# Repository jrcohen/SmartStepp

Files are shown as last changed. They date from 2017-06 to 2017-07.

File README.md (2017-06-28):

# SmartStepp

### Combination Driver and Encoder for Nema 17 stepper motors
Features:

 * Compact design mounts on the back of the motor
 * Chainable connections (12V Power, Logic Power, SPI) - Hook up multiple motors in series connected to just one microcontroller
 * Compatible with A4988 and DRV8825 stepper motor drivers
 * 14-bit magnetic encoder (AS5047d)
 * Encoder only version is RAMPS 1.4 compatible 

The aim of this project is to create inexpensive Nema 17 and Nema 23 motor encoders/drivers. These boards allow for plug-and-play stepper motor control with extremely precise position readouts once fully calibrated. 

Useful for 3D printers to provide higher precision movement and dynamic error correction for any missed steps (like if the printer gets bumped or stops mid-print).
Other potential applications include robotics/robot arms, process automation machines, hobby CNC machines, any other application needing precise repeatability under different loads.

Project hardware variants:

 * Motor driver only - target cost under $10
 * Encoder only - target cost under $15
 * Driver/Encoder combo - target cost under $20

Future Software compatibility:

 * Arduino Library
 * Python Library (for standalone raspberry pi use)
 * Marlin 
 * GRBL
 
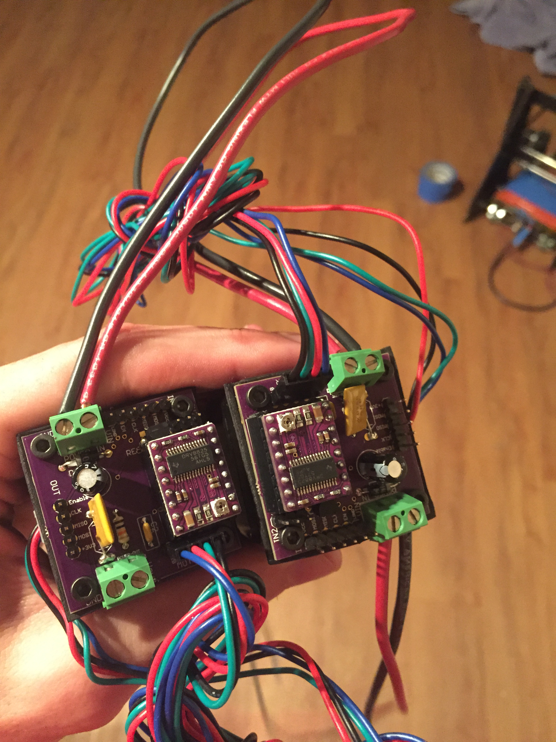
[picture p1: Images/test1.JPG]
Prototype


This project draws inspiration from [Mechaduino](https://github.com/jcchurch13/Mechaduino-Firmware/blob/master/README.md), but hopefully will have its own niche applications

Released under the Creative Commons Attribution Share-Alike 4.0 License

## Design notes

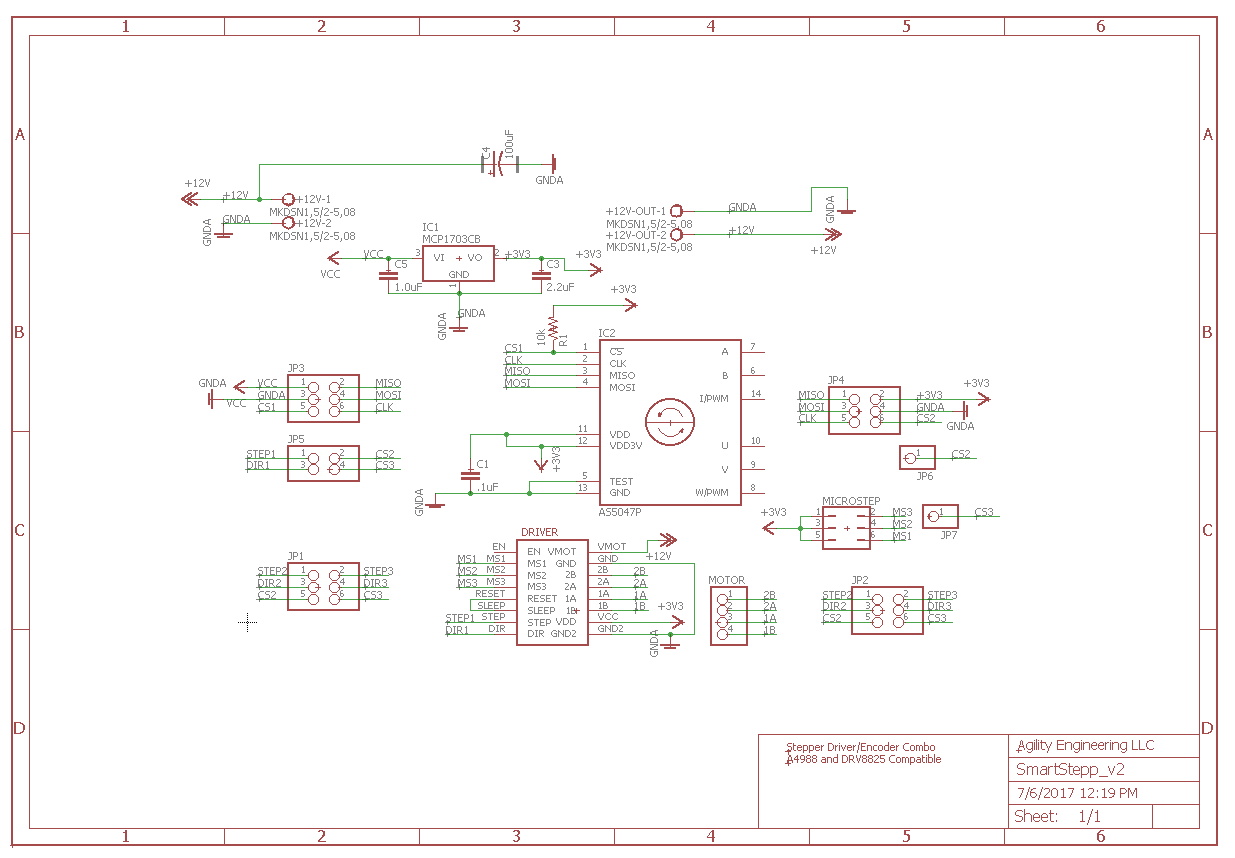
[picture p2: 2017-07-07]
Hardware/SmartStepp_V2_Schematic.PNG

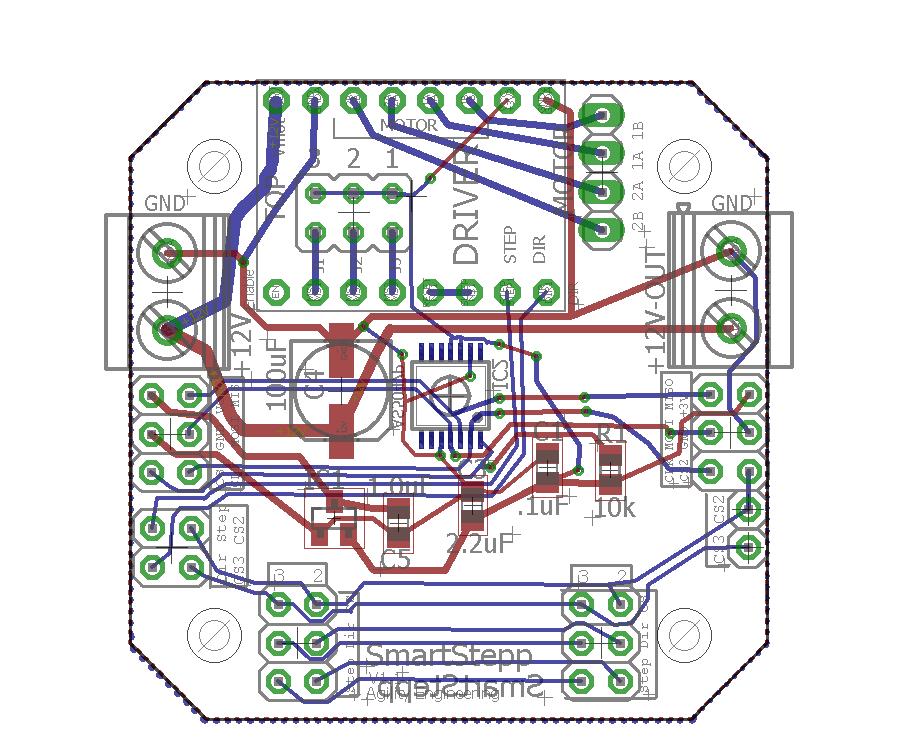
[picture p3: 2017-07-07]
Hardware/SmartStepp_V2_Board.PNG

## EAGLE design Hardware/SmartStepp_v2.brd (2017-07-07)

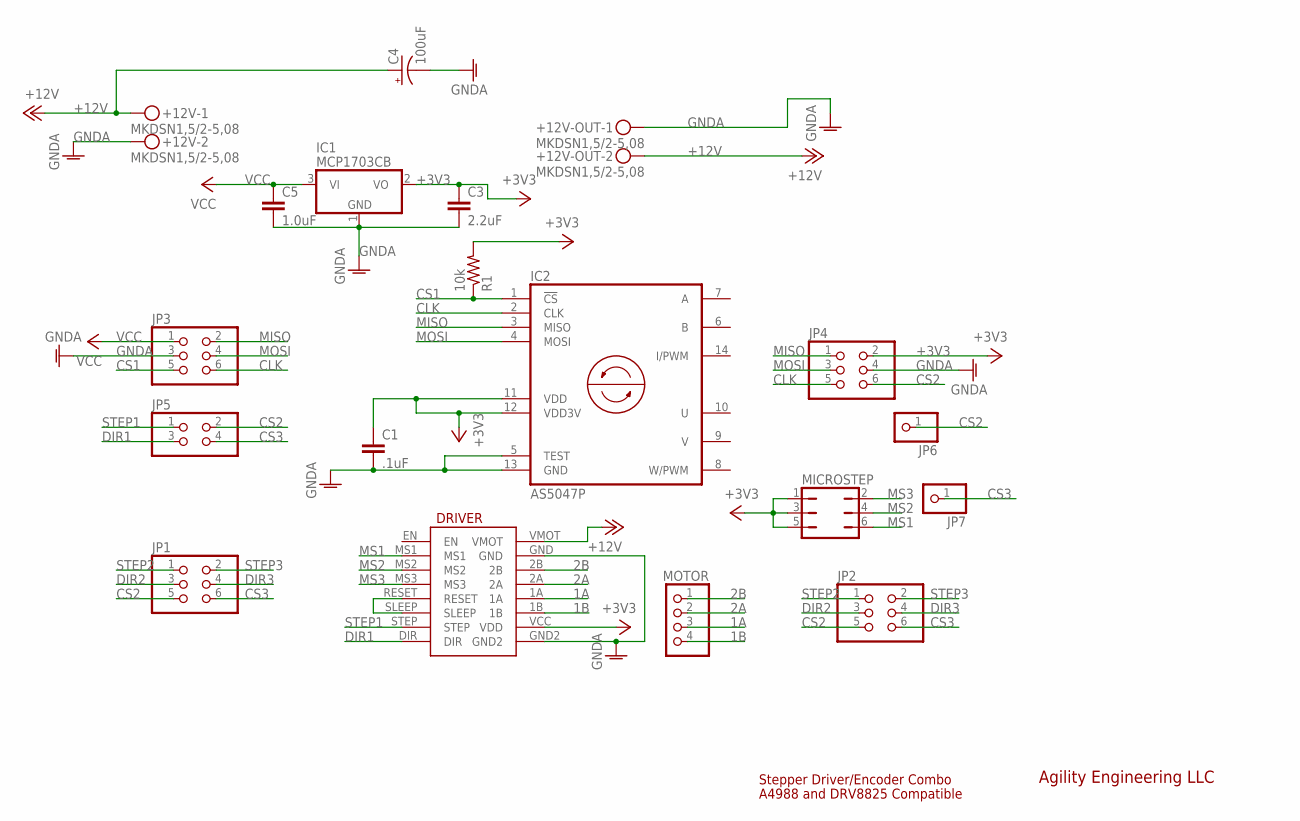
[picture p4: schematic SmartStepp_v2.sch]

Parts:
+12V, +12V-OUT: MKDSN1,5/2-5,08
C1: .1uF; C0805
C3: 2.2uF; C0805
C4: 100uF; 153CLV-0605
C5: 1.0uF; C0805
DRIVER: A4988; MOTOR_DRIVER
IC1: MCP1703CB; SOT23
IC2: AS5047P; TSSOP14
JP1, JP2, JP3, JP4: PINHD-2X3; 2X03
JP5: PINHD-2X2; 2X02
JP6, JP7: PINHD-1X1; 1X01
MICROSTEP: JP3Q
MOTOR: PINHD-1X4; 1X04
R1: 10k; R0805

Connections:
1A: DRIVER.1A, MOTOR.3
1B: DRIVER.1B, MOTOR.4
2A: DRIVER.2A, MOTOR.2
2B: DRIVER.2B, MOTOR.1
+3V3: C1.1, C3.1, DRIVER.VCC (VDD), IC1.2 (VO), IC2.11 (VDD), IC2.12 (VDD3V), JP4.2, MICROSTEP.1, MICROSTEP.3, MICROSTEP.5, R1.2
+12V: +12V.1, +12V-OUT.2, C4.+, DRIVER.VMOT
CLK: IC2.2 (CLK), JP3.6, JP4.5
CS1: IC2.1 (!CS!), JP3.5, R1.1
CS2: JP1.5, JP2.5, JP4.6, JP5.2, JP6.1
CS3: JP1.6, JP2.6, JP5.4, JP7.1
DIR1: DRIVER.DIR, JP5.3
DIR2: JP1.3, JP2.3
DIR3: JP1.4, JP2.4
GNDA: +12V.2, +12V-OUT.1, C1.2, C3.2, C4.-, C5.2, DRIVER.GND, DRIVER.GND2, IC1.1 (GND), IC2.5 (TEST), IC2.13 (GND), JP3.3, JP4.4
MISO: IC2.3 (MISO), JP3.2, JP4.1
MOSI: IC2.4 (MOSI), JP3.4, JP4.3
MS1: DRIVER.MS1, MICROSTEP.6
MS2: DRIVER.MS2, MICROSTEP.4
MS3: DRIVER.MS3, MICROSTEP.2
unnamed: DRIVER.RESET, DRIVER.SLEEP
STEP1: DRIVER.STEP, JP5.1
STEP2: JP1.1, JP2.1
STEP3: JP1.2, JP2.2
VCC: C5.1, IC1.3 (VI), JP3.1

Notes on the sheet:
Stepper Driver/Encoder Combo
A4988 and DRV8825 Compatible
Agility Engineering LLC

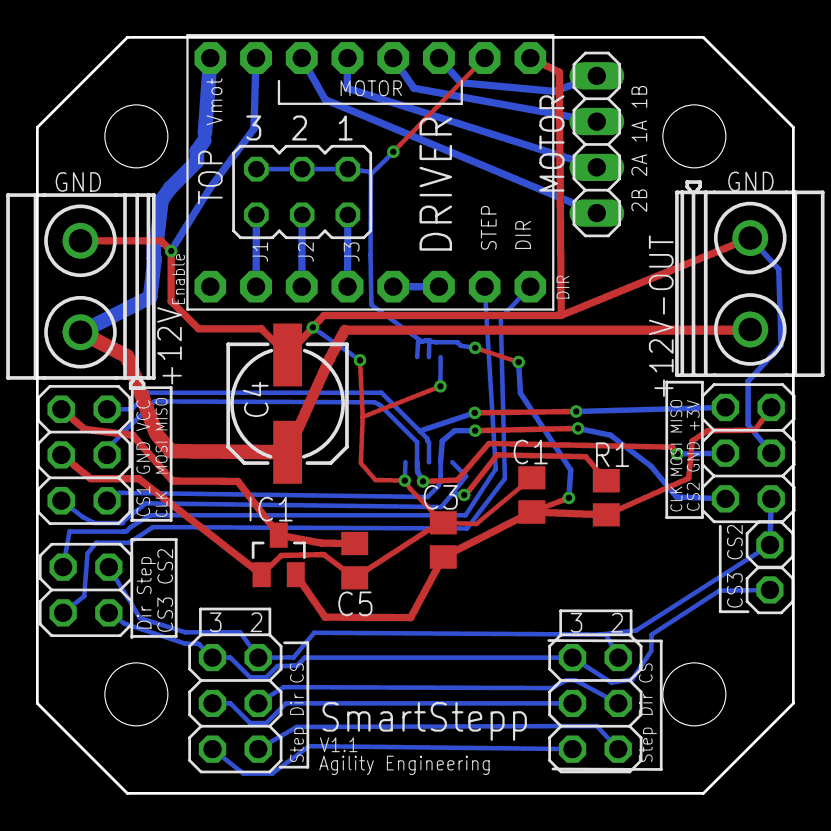
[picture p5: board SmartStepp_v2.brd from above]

Board: 2 copper layers, 42.0 x 42.0 mm, 19 parts (1 on the bottom side), 24 nets.

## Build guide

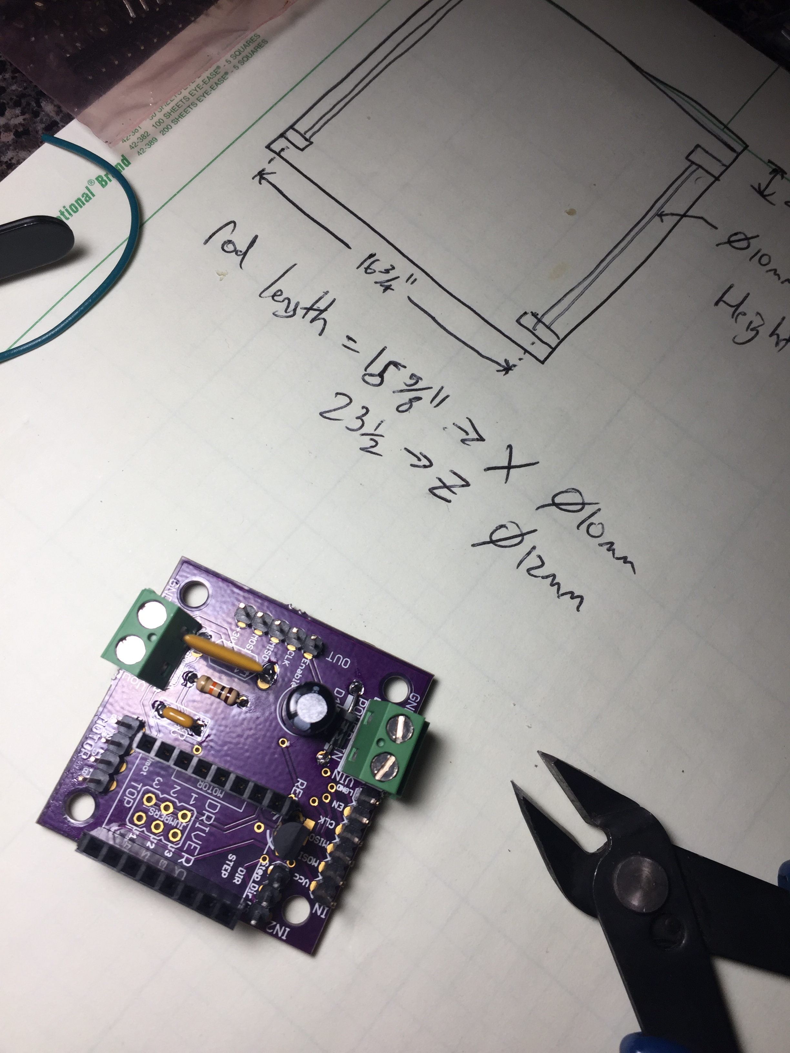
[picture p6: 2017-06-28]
Images/solder3.JPG

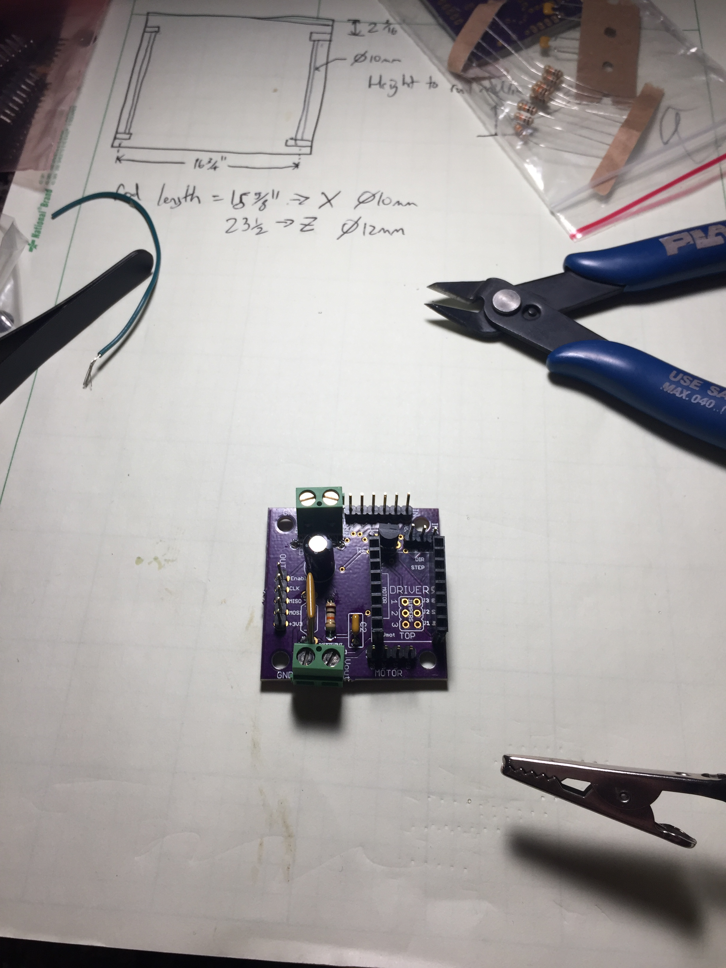
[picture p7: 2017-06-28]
Images/solder1.JPG

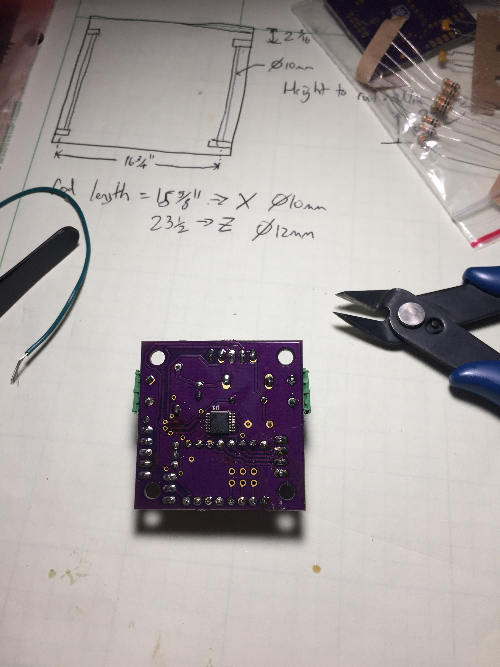
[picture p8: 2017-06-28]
Images/solder2.JPG

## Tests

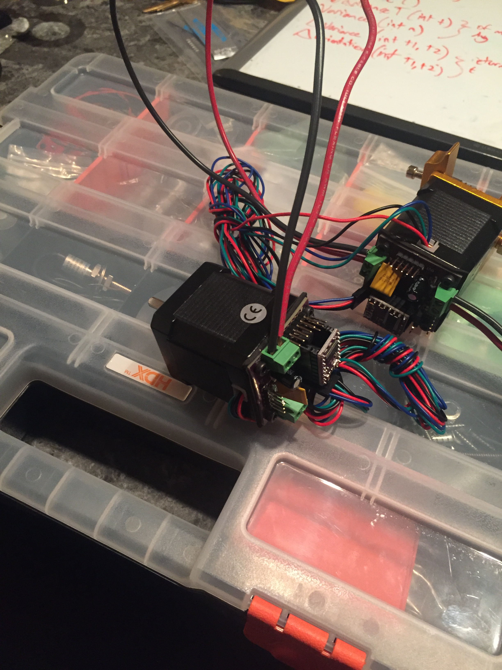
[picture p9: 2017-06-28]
Images/test3.JPG

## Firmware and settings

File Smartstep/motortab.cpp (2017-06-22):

#include <SPI.h>

#include "motorlib.h"
#include "Arduino.h"
#include "TableData.h"
#include <Math.h>

int motorlib::motorcount = 0;

motorlib::motorlib(int cspin, int step, int dir)
{
//  Serial.begin(9600);
  _cspin = cspin;
  _stepsetting = 32;
  _motortype = 1; // 1 for 1.8 deg/step and 2 for 0.9 deg/step
  _step = step;
  _dir = dir;
  _motornum = ++motorcount;
  if (_step == _dir){
    Serial.print("Step and Dir must be unique pins");
  }
  pinMode(_step, OUTPUT);
  pinMode(_dir, OUTPUT);
  pinMode(_cspin, OUTPUT);
  Serial.print("new motor: ");
  Serial.println(motorcount);
//  Serial.end();
  // To do later
  // Array of pins already in use by motors
  // For loop to check new pins and throw error message
  // Try/catch errors in pin assignments 
  // Try/Catch errors in motor and encoder function
}

motorlib::motorlib(int cspin, int stepsetting, int motortype, int step, int dir)
{
  Serial.begin(9600);
  _cspin = cspin;
  _stepsetting = stepsetting;
  _motortype = motortype; 
  _step = step;
  _dir = dir;
  _motornum = ++motorcount;
  if (_step == _dir){
    Serial.print("Step and Dir must be unique pins");
  }
  pinMode(_step, OUTPUT);
  pinMode(_dir, OUTPUT);
  Serial.print("new motor: ");
  Serial.println(motorcount);
  Serial.end();
}

void motorlib::moves(int steps)
{
//  Serial.begin(9600);
  if (steps < 0)
    digitalWrite(_dir, LOW);
  else
    digitalWrite(_dir, HIGH);
    
  for (int i = 0; i<abs(steps);i++) {
    digitalWrite(_step, LOW);
    delayMicroseconds(5);
    digitalWrite(_step, HIGH); 
    delayMicroseconds(600); 
  }
//  Serial.print("Moved ");
//  Serial.println(steps);
//  Serial.end();
}

void motorlib::movedeg(float deg)
{
  float type = 1.8/_motortype;
  int steps = round((deg/type)*_stepsetting);
  moves(steps);
}

float motorlib::getEncoderReading()
{
  digitalWrite(_cspin, LOW);
  byte half1 = SPI.transfer(0xFF);
  byte half2 = SPI.transfer(0xFF);
  digitalWrite(_cspin, HIGH);
  return (((half1 << 8) | half2) & 0B0011111111111111);
}

float motorlib::getAngleReading()
{ float sum = 0;
  int numreadings = 10;
  for (int i = 0; i < numreadings; i++) {
    sum += getEncoderReading();
    delay(10);
    }
  float avg = sum/numreadings;
  float angle = ((avg+16384)*360)/(32768);
  return angle;
}

float motorlib::getReading()
{ float sum = 0;
  int numreadings = 10;
  for (int i = 0; i < numreadings; i++) {
    sum += getEncoderReading();
    delay(20);
    }
  float avg = sum/numreadings;
  return avg;
}

void motorlib::setZero()
{
  float encoder = getEncoderReading();
  
}

void motorlib::runCalibration()
{
  
}

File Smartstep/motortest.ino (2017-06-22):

#include <SPI.h>
#include "motorlib.h"

  // put your setup code here, to run once:
  motorlib m1 = motorlib(8,10,9);
  motorlib m2 = motorlib(7,5,6);
  motorlib m3 = motorlib(3,4,12);
  float prev = 0;
  float curr = 0;
    int s = 1;
    
void setup() {
    
  Serial.begin(9600);
  SPI.begin();
  
  Serial.print("Starting: ");
  delay(2000);
  Serial.println(m1.getReading());
  delay(1000);
  Serial.println(m1.getReading());
  delay(1000);
  Serial.println(m1.getReading());
  delay(1000);
}

void loop() {
  int scale = 2048;
  Serial.println(s);
  m1.moves(s*scale);
  curr = m1.getReading();
  Serial.println(curr);
  Serial.print("Moved: ");
  if (curr-prev>0)
    Serial.println(8196-curr+prev);
//  else if (prev-curr>6000)
//    Serial.println(8196-prev+curr);
  else
    Serial.println(curr+8196-prev);
    
  prev = curr;
  delay(200);

  if (s >0){
    s = -1;
  }
  else {
    s = 1;
  }
  // put your main code here, to run repeatedly:
}

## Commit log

2017-06-22 Rename motorlib.h to Smartstep/motorlib.h
    Put file in folder
2017-06-22 Rename motortab.cpp to Smartstep/motortab.cpp
    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
2017-06-22 Rename motortest.ino.ino to Smartstep/motortest.ino
    Put file in folder and deleted duplicate .ino in filename
2017-07-07 Images of schematic and board files for StartStepp v1
2017-07-07 Board and schematic eagle files
    [SmartStepp_v2.brd, SmartStepp_v2.sch]
2017-07-07 test stage

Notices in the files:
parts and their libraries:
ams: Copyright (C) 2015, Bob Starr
